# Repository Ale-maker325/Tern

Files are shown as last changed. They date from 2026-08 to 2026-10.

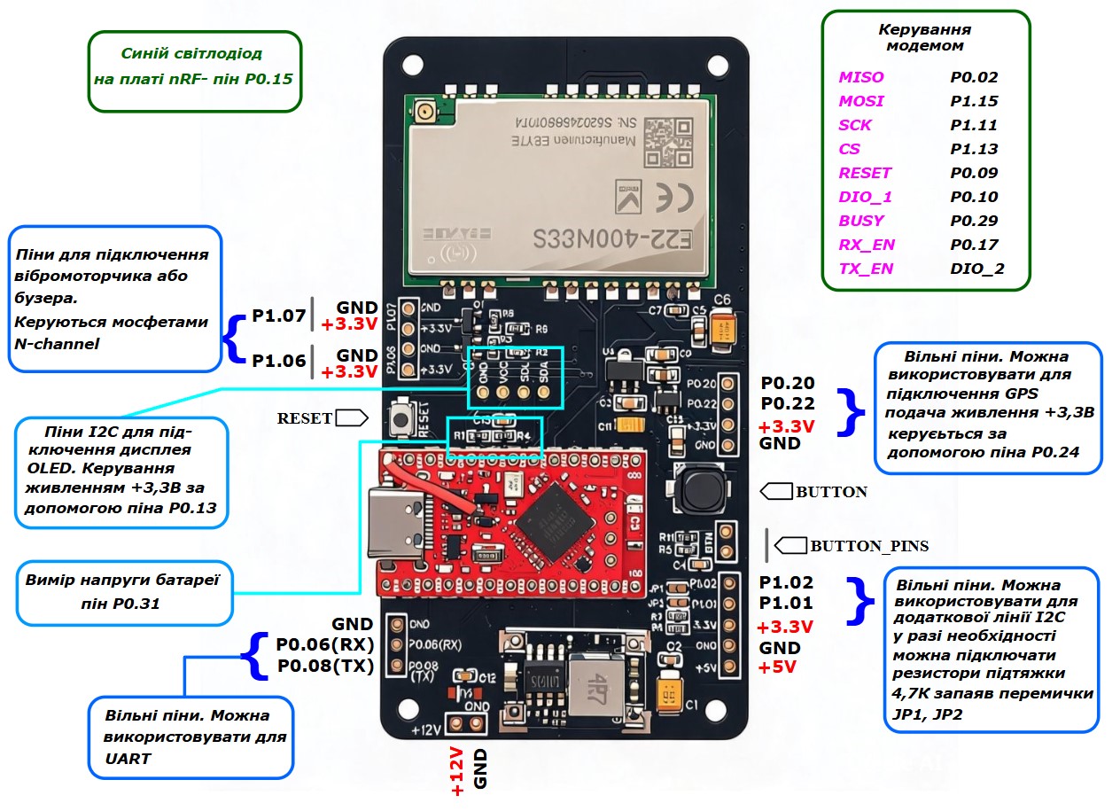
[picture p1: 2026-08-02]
assets/hardware/tern-nRF52840 ProMicro/Schematic_1.jpg

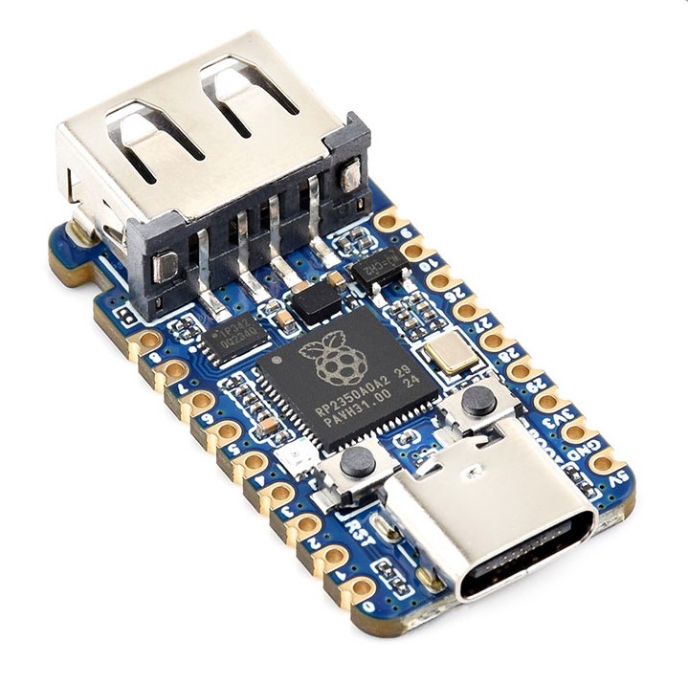
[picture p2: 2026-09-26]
assets/usb_keyboard/RP2350.jpg

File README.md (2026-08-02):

# Екосистема апаратури Tern та прошивки MLT-2

**Tern** — це екосистема компактних кастомних плат та автономних тактичних LoRa-комунікаторів, розроблена для роботи в умовах відсутності базової інфраструктури, високого рівня перешкод та складних польових умов.

Проєкт об'єднує в собі апаратну платформу **Tern** (на базі мікроконтролерів nRF52840 / ESP32-S3 та радіомодемів Ebyte E22/SX126x) та спеціалізовану прошивку **MLT-2** (Mesh Tactical Protocol v2).

---

## 📌 Ключові особливості MLT-2

- **Дворівнева модель довіри:** Суворе розмежування загальної бази пристроїв (Directory) та оперативного списку зв'язку («Книга» / Active Roster).
- **Радіомаскування:** Одноканальна broadcast-передача зашифрованих пакетів без відкритих підтверджень (ACK), які демаскують групу в ефірі.
- **Наскрізне шифрування:** Криптозахист корисного навантаження (payload) на базі AES-128-CBC з динамічним детермінованим IV (без передачі IV в ефір).
- **Автономний UI:** Повне налаштування та управління мережею через OLED-дисплей однією кнопкою, BLE-UART або текстовий CLI-термінал.

---

## 📚 Документація та Wiki

Вихідний код прошивки розповсюджується у вигляді готових скомпільованих бінарних збірок (Releases). Повний посібник користувача, специфікація протоколу та інструкції з інтеграції винесені в **[GitHub Wiki](../../wiki)**.

### Структура документації (Wiki):

1. **[Прошивка MLT-2](../../wiki/MLT2-Firmware-Overview)**
   - [Концепція та принципи безпеки](../../wiki/MLT2-Security-Principles)
   - [Специфікація протоколу MLT](../../wiki/MLT2-Protocol-Specification)
   - [Модель шифрування та криптозахист](../../wiki/MLT2-Crypto-Architecture)
   - [Інтерфейс OLED та управління кнопкою](../../wiki/MLT2-Display-and-UI)
   - [BLE-UART та прив'язка нод (Binding)](../../wiki/MLT2-BLE-Interface)
   - [Командний інтерфейс CLI (@-команди)](../../wiki/MLT2-CLI-Reference)
2. **[Апаратні плати Tern](../../wiki/Tern-Hardware-Overview)**
   - [Tern-N52 (nRF52840 Pro Micro + E22)](../../wiki/Tern-N52-Pinout)
   - [Псевдокод та приклади ініціалізації периферії](../../wiki/Tern-Hardware-Examples)
3. **[Інтеграція з екосистемою Meshtastic](../../wiki/Meshtastic-Integration)**
   - [Конфігураційні файли (variant.h / variant.cpp)](../../wiki/Meshtastic-Variant-Files)
   - [Інструкція зі збірки прошивки Meshtastic під плати Tern](../../wiki/Meshtastic-Build-Guide)

---

## 💾 Збірки прошивки (Releases)

Готові файли прошивок для завантаження доступні в розділі **[Releases](../../releases)**. 
Завантаження здійснюється через стандартний `nrfutil` / UF2-bootloader (для nRF52) або `esptool` (для ESP32-S3).

---

## ⚖️ Ліцензування та дисклеймер

- **MLT-2 Firmware Binaries & Documentation:** Розповсюджуються під ліцензією [MIT License](LICENSE).
- **Meshtastic Integration Files:** Всі файли конфігурації та адаптації під проєкт Meshtastic є частиною екосистеми Meshtastic і розповсюджуються під ліцензією **GNU GPLv3**.
- **Hardware & 3D Models:** Всі креслення, схеми та 3D-моделі корпусів розповсюджуються під ліцензією **CC BY-NC-ND 4.0**.

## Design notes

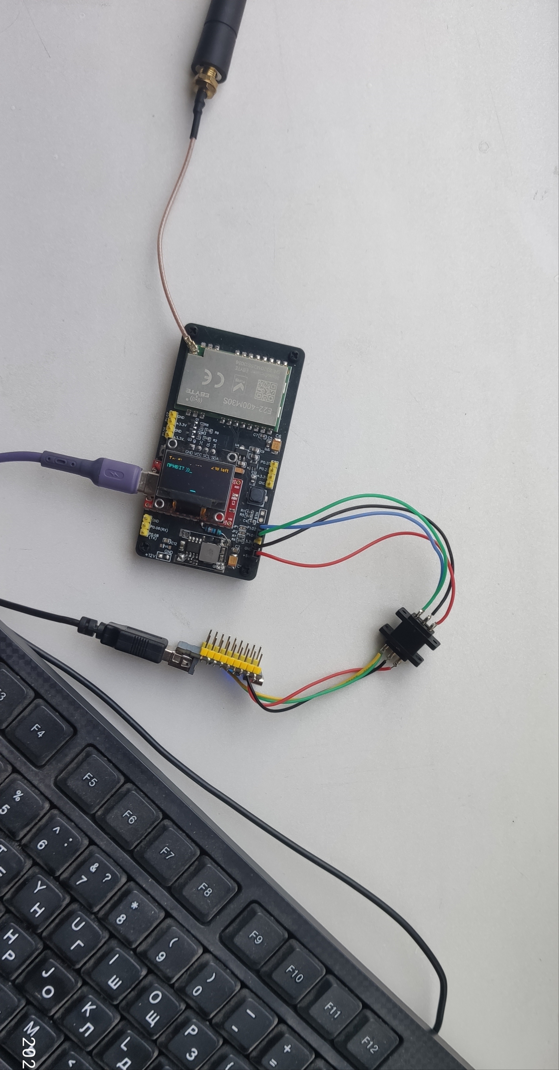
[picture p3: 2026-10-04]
assets/usb_keyboard/tern_keyboard_connected.jpg

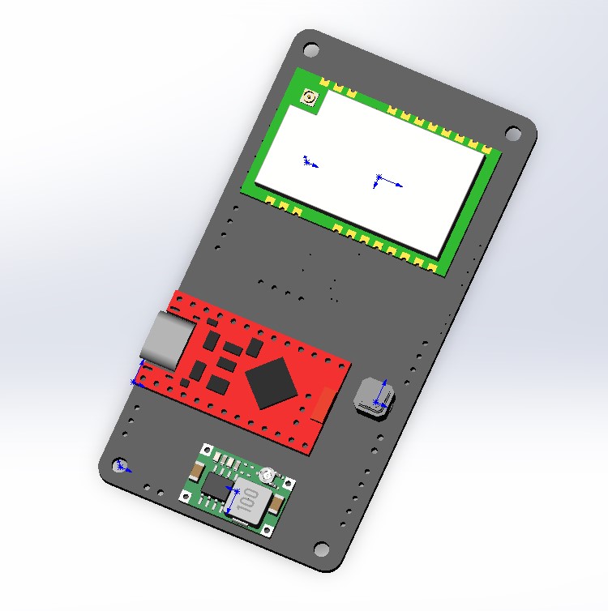
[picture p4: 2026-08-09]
3D Model/3D_model_board.jpg

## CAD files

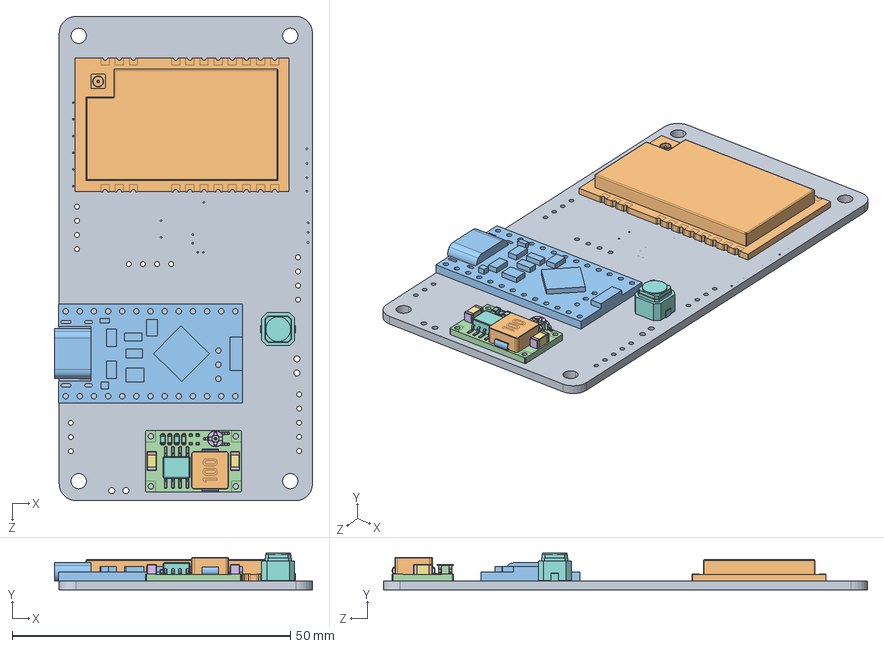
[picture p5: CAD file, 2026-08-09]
3D Model/board_nRF52840_ProMicro.STEP
46.3 x 6.60 x 87.0 mm
board
E22-900M30S
Pro_Micro_
DSN-MINI-360__
Tactle Switch 6x6mm - Soft

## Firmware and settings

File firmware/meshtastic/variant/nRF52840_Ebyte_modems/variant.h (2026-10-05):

#ifndef _VARIANT_PROMICRO_DIY_
#define _VARIANT_PROMICRO_DIY_

//----------------------------------------------------------------------------------------//
//----------------------- ТАКТУВАННЯ ТА ЗАГАЛЬНІ НАЛАШТУВАННЯ ПЛАТИ ---------------------//
//----------------------------------------------------------------------------------------//

/** Частота опорного генератора схеми синхронізації мікроконтролера (Master clock) */
#define VARIANT_MCK (64000000ul)

// Налаштування джерела низькочастотного тактування (LF)
// За замовчуванням — внутрішній RC-генератор: працює на будь-якій платі ProMicro.
// Якщо на платі ТОЧНО є кварц 32,768 кГц на виводах P0.00/P0.01 (не плутати з кварцем 32 МГц,
// який є на будь-якій nRF52840), можна увімкнути USE_LFXO замість USE_LFRC: трохи менше споживання
// і точніший час BLE. Без цього кварцу вузол з USE_LFXO не запуститься — тоді повернути USE_LFRC і
// прошити заново через завантажувач (подвійне натискання reset).
// #define USE_LFXO // Зовнішній кварц 32,768 кГц
#define USE_LFRC // Плата використовує внутрішній RC-генератор мікроконтролера для низьких частот

// PROMICRO_DIY_TCXO навмисно НЕ задано: він вмикає визначення USB за лінією VBUS nRF52840, а на
// цій платі 5 В від знижувального перетворювача (MP2225) постійно надходять на VBUS. Вузол вважав би,
// що USB підключено завжди: блимала б блискавка заряду і не працював би захист батареї від розряду.
// Без нього «USB» = напруга батареї вища за першу точку OCV_ARRAY + 10 мВ (2S: 8,39 В).
// #define PROMICRO_DIY_TCXO

/*----------------------------------------------------------------------------
 * Заголовки системних визначень
 *----------------------------------------------------------------------------*/

#include "WVariant.h"

#ifdef __cplusplus
extern "C" {
#endif // __cplusplus

//----------------------------------------------------------------------------------------//
//----------------------------------- ТАБЛИЦЯ ПІНІВ -------------------------------------//
//----------------------------------------------------------------------------------------//

/*
ПРИЗНАЧЕННЯ ПІНІВ МІКРОКОНТРОЛЕРА NRF52 PRO MICRO (ФІЗИЧНА СХЕМА ПІДКЛЮЧЕННЯ)

| Pin   | Функція МК           |     | Pin      | Функція                |
| ----- | -------------------- | --- | -------- | ---------------------- |
| Gnd   | Земля                |     | vbat     | Живлення бат.          |
| P0.06 | Serial2 RX           |     | vbat     | Живлення бат.          |
| P0.08 | Serial2 TX           |     | Gnd      | Земля                  |
| Gnd   | Земля                |     | reset    | Скидання МК            |
| Gnd   | Земля                |     | ext_vcc  | Живлення пер. (P0.13)  |
| P0.17 | RXEN                 |     | P0.31    | BATTERY_PIN            |
| P0.20 | GPS_RX (= TX МК)     |     | P0.29    | BUSY                   |
| P0.22 | GPS_TX (= RX МК)     |     | P0.02    | MISO                   |
| P0.24 | GPS_EN               |     | P1.15    | MOSI                   |
| P1.00 | BUTTON_PIN           |     | P1.13    | CS                     |
| P0.11 | SCL                  |     | P1.11    | SCK                    |
| P1.04 | SDA                  |     | P0.10    | DIO1/IRQ               |
| P1.06 | MOSFET (бузер/вібро) |     | P0.09    | RESET                  |
|       |                      |     |          |                        |
|       | Середина             |     |          | Внутрішні              |
| P1.01 | Вільний              |     | 0.15     | LED                    |
| P1.02 | Вільний              |     | 0.13     | 3V3_EN                 |
| P1.07 | MOSFET (бузер/вібро) |     |          |                        |

TXEN модема не виведено на МК: передачу/прийом перемикає сам чип через DIO2
(SX126X_DIO2_AS_RF_SWITCH), тому P1.06 вільний під MOSFET.
Назви GPS_RX / GPS_TX дано з точки зору GPS-модуля: лінія «GPS_RX» (P0.20) іде на вхід
модуля GPS, тобто це передача МК; лінія «GPS_TX» (P0.22) приходить з виходу модуля GPS,
тобто це прийом МК.
*/

//----------------------------------------------------------------------------------------//
//----------------------- ДОВІДКА: КОМАНДНИЙ РЯДОК MESHTASTIC (CLI) ---------------------//
//----------------------------------------------------------------------------------------//

/*
 * Команди з коментарів цього файлу виконуються утилітою `meshtastic` (Python).
 *
 * Встановлення у Windows (один раз):
 *   1. Завантажити Python 3 з https://www.python.org/downloads/ і під час встановлення
 *      ОБОВ'ЯЗКОВО поставити позначку «Add python.exe to PATH».
 *   2. Відкрити нове вікно «Командний рядок» (cmd) і виконати:
 *        pip install --upgrade "meshtastic[cli]"
 *   3. Перевірити:  meshtastic --version
 *   Оновлення утиліти — та сама команда pip. Драйвер для плати не потрібен: у nRF52840
 *   вбудований USB, Windows 10/11 сама створює COM-порт.
 *
 * Підключення:
 *   - Плата по USB, застосунок/монітор порту (PlatformIO, Arduino) ЗАКРИТІ — порт
 *     може займати лише одна програма.
 *   - Якщо COM-портів кілька, вказати потрібний:  meshtastic --port COM7 --info
 *   - Через Bluetooth:  meshtastic --ble "ім'я_вузла" --info
 *
 * Загальні команди:
 *   meshtastic --info                  — уся інформація про вузол і налаштування
 *   meshtastic --nodes                 — таблиця вузлів мережі (SNR, батарея, час)
 *   meshtastic --get device            — прочитати розділ налаштувань (device, lora, position, power...)
 *   meshtastic --set розділ.поле значення — змінити налаштування; кілька --set в одній
 *                                        команді застосовуються разом
 *   meshtastic --noproto               — дивитися налагоджувальний лог прошивки (вихід: Ctrl+C)
 *   meshtastic --reboot                — перезавантажити вузол
 *   meshtastic --export-config > backup.yaml   — зберегти всі налаштування у файл
 *   meshtastic --configure backup.yaml         — відновити налаштування з файлу
 *
 * Номер піна в командах = порт * 32 + вивід: P0.15 → 15, P1.02 → 34, P1.06 → 38.
 */

//----------------------------------------------------------------------------------------//
//------------------------------- КІЛЬКІСТЬ ВИВОДІВ МК ----------------------------------//
//----------------------------------------------------------------------------------------//

// Загальна кількість цифрових і аналогових виводів, визначених у системі
#define PINS_COUNT (48)
#define NUM_DIGITAL_PINS (48)
#define NUM_ANALOG_INPUTS (1)
#define NUM_ANALOG_OUTPUTS (0)

//----------------------------------------------------------------------------------------//
//----------------------------- ЖИВЛЕННЯ ПЕРИФЕРІЇ 3,3 В --------------------------------//
//----------------------------------------------------------------------------------------//

// P0.13 керує MOSFET-ключем плати ProMicro, який подає 3,3 В на дисплей і його шину I2C
// (або на інший пристрій, якщо дисплея немає). Більше від цього ключа нічого не живиться.
#define PIN_3V3_EN (0 + 13) // P0.13
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

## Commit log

2026-08-02 Create .gitkeep
    Добавлена папка firmware/meshtastic/.gitkeep
2026-08-02 Create .gitkeep
    Добавлена папка firmware/tern/.gitkeep
2026-08-02 Create .gitkeep
    добавлена папка assets/hardware/tern-nRF52840 ProMicro/.gitkeep
2026-08-08 Create 2.7.15
    добавлена версия папок для прошивки 2.7.15
2026-08-08 Delete firmware/meshtastic/2.7.15
    удален
2026-08-08 Create .gitkeep
    Добавлена папка 2.7.15
2026-08-08 Create .gitkeep
    добавлена папка 2.7.26
2026-08-08 Add files via upload
    Добавлена прошивка 2.7.26
2026-08-08 Create .gitkeep
    Добавлена папка для файла очистки флеш-памяти
2026-08-08 Add files via upload
    Добавлен файл для очистки памяти
2026-08-09 Create .gitkeep
    Додано папку для моделей 3Д
2026-08-09 Add files via upload
    Додано 3Д модель плати
    [board_nRF52840_ProMicro.STEP]
2026-09-26 Додано прошивку контролера USB-клавіатури RP2350-USB-A та фото плати
    Прошивка firmware_RP2350_USB.uf2 та фото RP2350.jpg скопійовано з репозиторію Radio-Zero-v2
    для сторінки вікі про підключення USB-клавіатури до Meshtastic на tern-nRF52840 ProMicro.
2026-09-26 Додано файли варіанта Meshtastic для tern-nRF52840 ProMicro (nRF52840_Ebyte_modems)
    variant.h, variant.cpp, platformio.ini — актуальна версія: батарея 2S/3S через OCV_ARRAY, вимкнено PROMICRO_DIY_TCXO,
    друга шина I2C та USB-клавіатура (ENABLE_KEYBOARD_I2C), український шрифт OLED, коментарі з командами CLI.
2026-09-26 Видалено застарілі прошивки Meshtastic 2.7.15
2026-09-26 Оновлено прошивку Meshtastic 2.7.26 для tern-nRF52840 ProMicro (батарея 2S, без USB-клавіатури)
    Нова збірка: правильні напруга та відсотки 2S (OCV_ARRAY), працює захист від глибокого розряду,
    без хибного «USB» (вимкнено PROMICRO_DIY_TCXO), український шрифт OLED, GPS вимкнений за замовчуванням.
2026-09-26 Перейменовано прошивку 2.7.26: у назві вказано батарею 2S
2026-09-26 Додано прошивку Meshtastic 2.7.26 з підтримкою USB-клавіатури (батарея 2S)
    Друга шина I2C на P1.02 / P1.01, клавіатура CardKB-сумісна (адреса 0x5F) через контролер RP2350-USB-A,
    розкладка EN/UA, затримка старту 2 с для контролера клавіатури.
2026-10-04 Фото ноди tern-nRF52840 ProMicro з USB-клавіатурою
2026-10-05 Прошивка Meshtastic 2.7.26 для батареї 3S з підтримкою клавіатури
2026-10-05 variant.h: регіон 868 (EU_868 / UA_868, QR спільноти), межа потужності чипа SX126X_MAX_POWER 21
